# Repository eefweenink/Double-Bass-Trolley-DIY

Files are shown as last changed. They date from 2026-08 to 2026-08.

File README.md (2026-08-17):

# Double Bass Trolley DIY
**Manual + Downloads to Build Your Own Double Bass Trolley** *(Work in Progress)*

---

## Introduction

About ten years ago, I purchased one of the last available **Double Trolley** models by [Marc Grue](https://www.doubletrolley.com). It was a fantastic combination: a trolley with large, sturdy wheels that made it easy to walk—even up and down stairs—with an integrated stool. While the seat took some getting used to (it’s a bit small), it worked perfectly for me.

However, over time, my Double Trolley has started to wear out. Unfortunately, it’s no longer available for purchase, and secondhand models are nearly impossible to find. I understand why: if something works well, you don’t just let it go.

After years of searching for a suitable replacement without success, I decided to take matters into my own hands and build one myself. For now, this design does not include a stool, but the flexibility of 3D printing means I can easily adapt it later. I might even integrate it with an existing stool, allowing me to transport both my double bass and stool as a single unit.

This is my current design, which I’m actively testing. My goal is to share the design, bill of materials (BOM), and STL files so that other double bassists can build and enjoy their own version.

Regards,  
Eef

Double Bass Trolley Design

---

## Wheel Selection and Bearing Housing

### Wheel Choice
Without wheels, there’s no trolley. **12-inch wheels** are ideal: large enough to clear bumps but not so large that they compromise flexibility. This size also makes them perfect for navigating stairs.

For reference, [this Amazon listing](https://www.amazon.nl/Achterwiel-reservewiel-fietsbanden-veelzijdige-toepassing/dp/B0F9J1QZNZ) shows what these wheels look like. I found mine on **Marktplaats** (a Dutch second-hand marketplace), attached to a child’s bike.

### Wheel Construction
The wheel (plastic) contains two **6001ZZ bearings** pressed into either side, with the following dimensions:
- **Outer diameter**: 28 mm
- **Inner diameter**: 12 mm
- **Height**: 8 mm
- **Outer diameter of the inner ring**: 16.5 mm

### Securing the Wheel
To secure the wheel unilaterally in a tube, I use **M12 bolts** and 3D-printed bushings/plugs. The assembly (from left to right) consists of:
1. A **seal** that fits inside/on the tube.
2. A **flexible ring** that fits snugly into the bushing.
3. A **cone** that pushes the ring outward, clamping it in place.
4. A **self-locking nut** that holds the wheel in place while pressing all components together.

Assembly Diagram

To ensure this works with a single bolt, the design must include a column of components that can push against each other **without displacing or clamping the bearings**. This is achieved with the following structure:
- **Green**: The axle (an M12 bolt).
- **Red**: The bearings.
- **Blue**:
  - **Shim rings** (middle section): Must fit precisely on the inner ring of the bearing.
  - **Bearing housing**: Fits snugly on the inner ring and transfers pressure to the tube seal.

Bearing Housing Diagram

### Dimensions and Tolerances
- **General tolerance**: ±0.1 mm
- **Shim rings**:
  - **Inner diameter**: Slightly larger than 12 mm (target: **12.1 mm**).
  - **Outer diameter**: Maximum **17 mm**.
  - **Thickness**: **1.5–2 mm**.
- **Bearing housing**:
  - **Inner diameter**: Slightly larger than 12 mm (target: **12.1 mm**).
  - **Outer diameter**: Can be larger (up to **20 mm**; a wall thickness of **3–4 mm** is substantial).
    - *Note*: If the outer diameter exceeds 17 mm, **chamfer the ends** to avoid pressing on the wrong parts of the bearings.
  - **Thickness**: **34 mm** (so the total height of two bearings (2 × 8 mm) + housing equals **50 mm**).
    - **Important**: Measure first! Depending on the wheels, the thickness might need slight adjustment to avoid pressure on the bearings. Use your slicer to scale the model to the correct size if necessary.

Dimensions Diagram

> *The bearing housing and shim rings can be 3D printed or made of metal. My suggestion is to 3D print the bearing housing and use metal shims (see BOM list).*

---

## Materials Used

### Structural Components
- **Aluminum tube**:
  - **Outer diameter**: 33.3 mm
  - **Wall thickness**: 3 mm
  - **Purpose**: Used as the axle for mounting the wheels (see [Securing the Wheel](#securing-the-wheel)). Together with three other sections, it forms a sturdy rectangular frame that serves as the base of the trolley.
  - **Dimensions**:
    - **Axle length**: 38 cm (for my double bass in its bag).
    - **Vertical tubes**: 50 cm each (two pieces). May also be longer, about 65 cm so the top crossbar comes above the upper bout.
    - **Top crossbar**: ~31.3 cm (calculated as `38 cm - (2 × 33.3 mm)`).
- **Tyleen tubing**:
  - **Diameter**: 20.2 mm
  - **Purpose**: Used to build the side supports. This tubing has a **fixed curvature**, so it is important to rotate the pieces favorably during assembly.
 
- **Underfloor heating hose**:
  - **Diameter**: 16 mm
  - **Purpose**: The double bass rests on **half-moon-shaped parts** that are held together by this hose. See the image below for clarification.

  Half-moon shaped parts with hose

### 3D-Printed and Fastening Components
- **PETG filament**:
  - All couplings and connecting parts are 3D-printed using PETG.
  - **Printer volume**: 12 × 12 × 12 cm (all parts fit within this build volume, so no large printer is required).
- **Fastening cord**:
  - **Material**: 3.5 mm **paracord** (with a tensile strength of **150 kg**, more than sufficient for a double bass).
  - **Setup**:
    - **Lower loop**: Passes through the tubes and around the end pin.
    - **Upper loop**: Passes through the tubes and, using a **"spin elastic/span band"**, secures the neck.
    - Both loops pull in **opposite directions**, pressing the tube system firmly together toward the center.

### Additional Hardware
- **Metal hook**: Used to attach the cord to the end pin.
- **2 × M12 bolts**: For securing the wheel assembly.
- **4 × shim rings**: Prevent the force from the wheel mounting from pressing on the outer side of the bearings.

---

## End Hook and Accessories for Easy Spin Attachment
Printing Setup

The trolley is secured at the bottom with a hook around the **end pin**. Finding a well-fitting hook for this purpose isn’t straightforward, but this [hook from Amazon](https://www.amazon.nl/dp/B0C6HJWLKB) works reasonably well.

However, during use, the cord tends to slip between the iron wires of the hook, causing it to bend out of shape. To solve this, I designed a **protective "donut"** that shields the hook.
End pin hook with protective donut

### Printing the Donut
To print the donut:
1. **Positioning the hook**: The hook must be placed at the correct height inside the donut. This is easily achieved by using a **pause feature in the slicer**.
2. **Support structure**: Add **manual support** (only for the bottom surface, using the "tree" support type) to the donut in the slicer.
3. **Alignment tool**: Use a **1 mm thin rod** of the correct length to ensure the donut is printed at the right height.
4. **Printing process**:
   - Pause the print at the designated height.
   - Insert the hook neatly into the donut.
   - Resume the print.
Hook Example

Donut and Hook Assembly

> **Note**: The same design is used to create rings for the **top section**, making it easy to hook in the spin elastic.
Donut Design

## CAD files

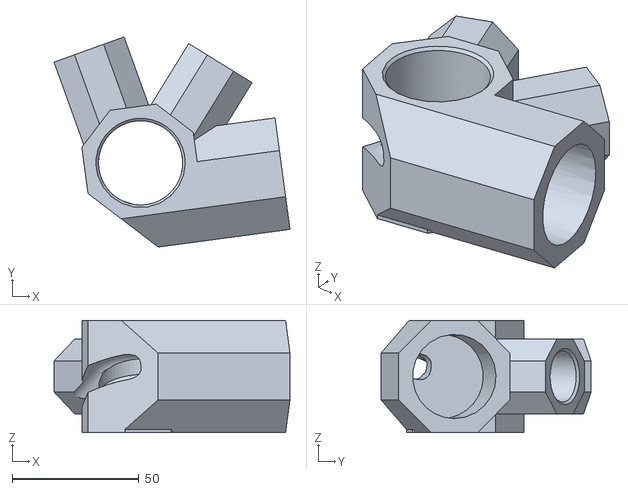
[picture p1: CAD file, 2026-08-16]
STL's/Alu construct/axle alu connector R (1x).stl
93.1 x 82.9 x 44.3

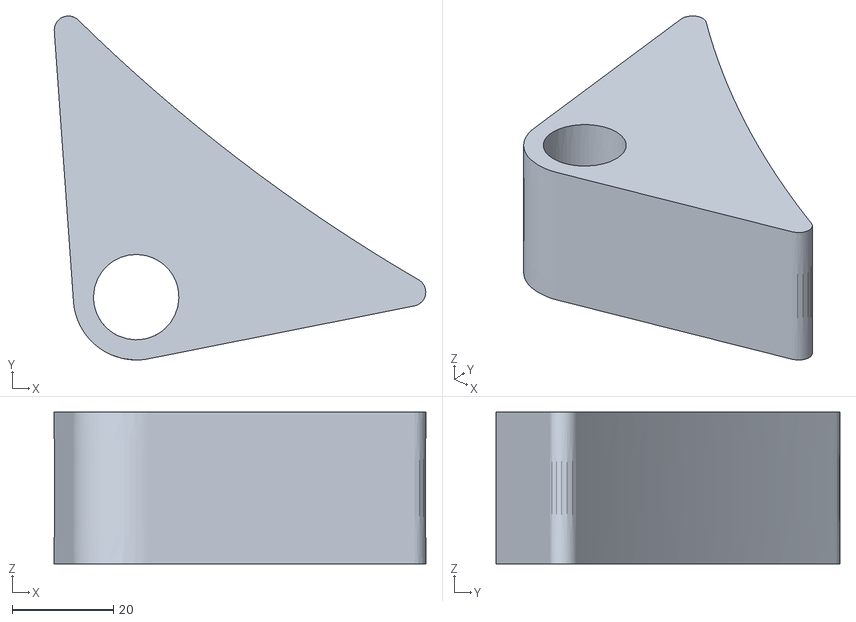
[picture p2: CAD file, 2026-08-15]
STL's/holder/bass holder (4x).stl
73.6 x 68.1 x 30.0

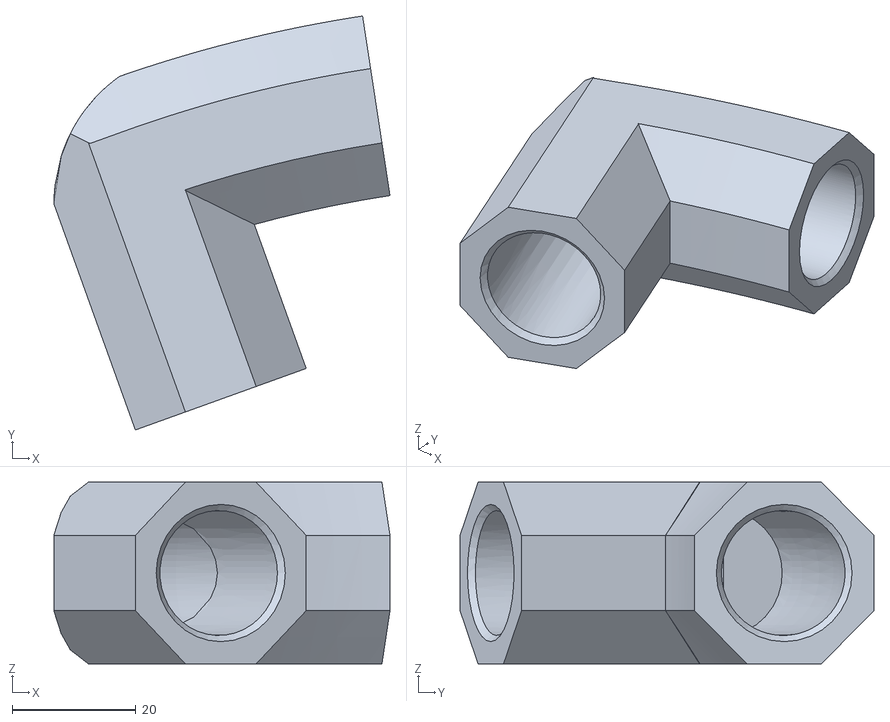
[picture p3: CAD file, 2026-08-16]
STL's/Sideskirt/skirt - knee (2x).stl
54.3 x 67.0 x 29.4

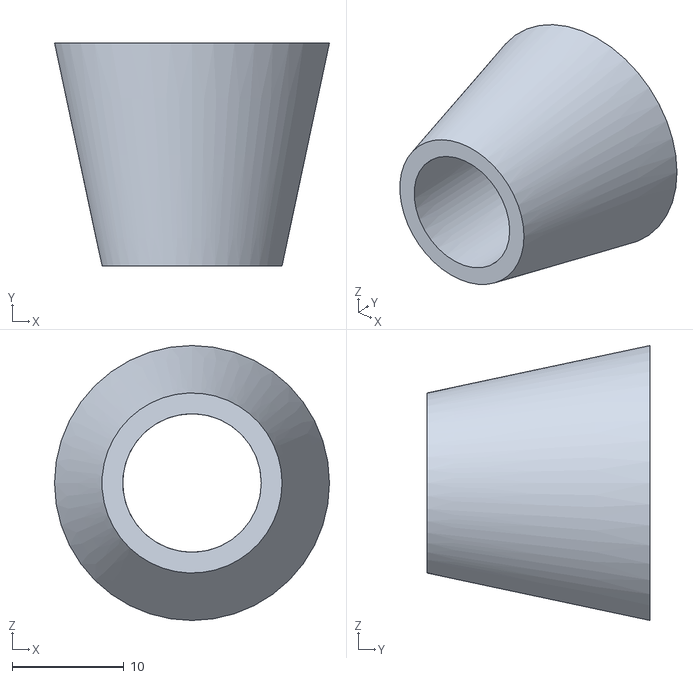
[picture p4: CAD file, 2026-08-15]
STL's/wheel-axle/wheel-axle plug tapered part (2x).stl
24.6 x 20.0 x 24.6

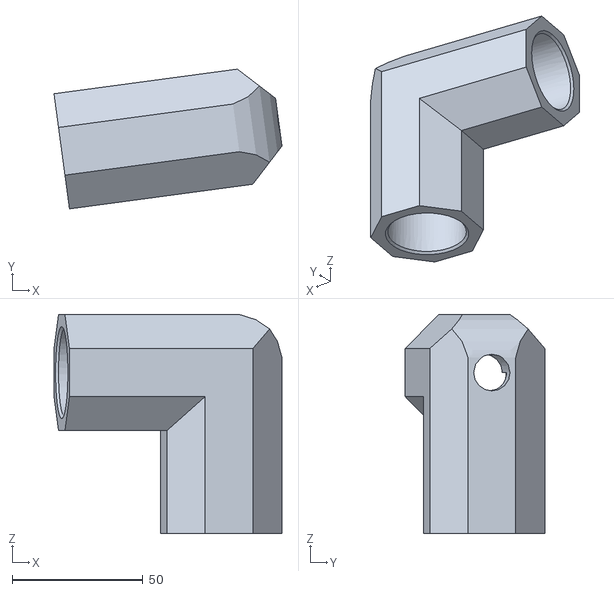
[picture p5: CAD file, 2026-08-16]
STL's/Alu construct/top bar alu connector (2x).stl
87.1 x 53.4 x 83.6

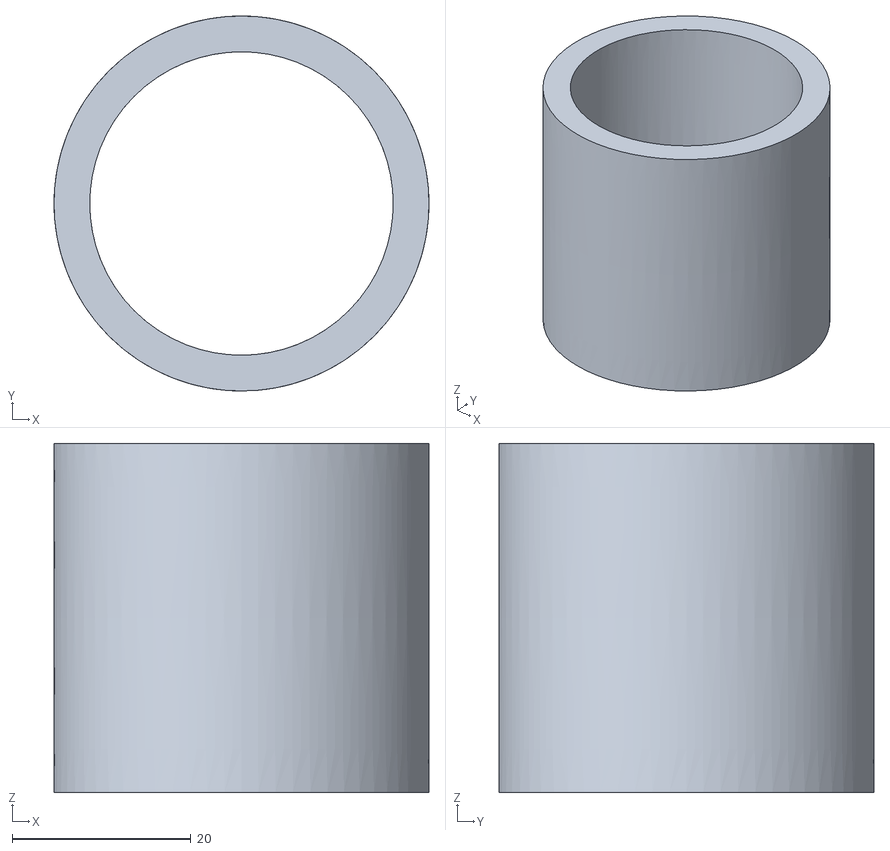
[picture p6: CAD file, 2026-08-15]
STL's/holder/spacer sleeve 39mm (2x).stl
41.9 x 41.9 x 39.0

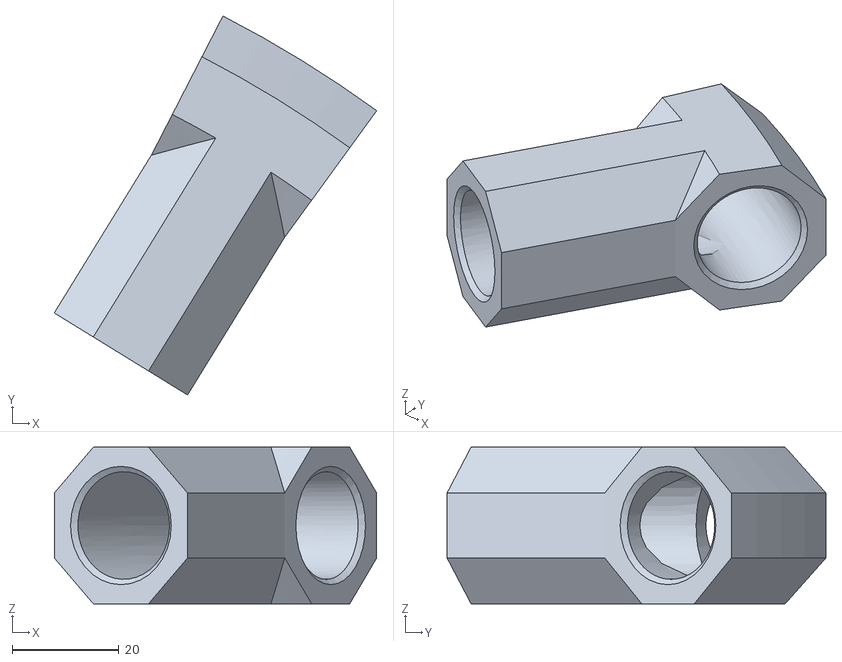
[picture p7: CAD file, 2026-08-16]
STL's/Sideskirt/skirt - T-part (2x).stl
60.5 x 71.1 x 29.4

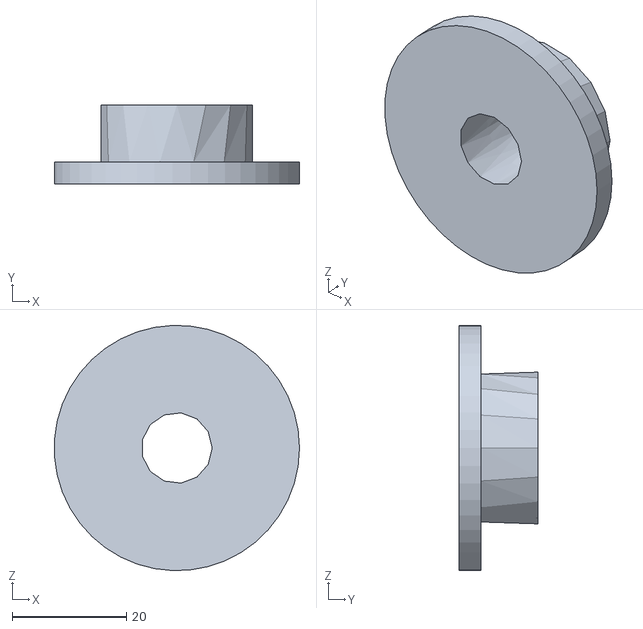
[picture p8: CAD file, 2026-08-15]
STL's/wheel-axle/wheel-axle plug outer part (2x).stl
42.9 x 13.9 x 43.0

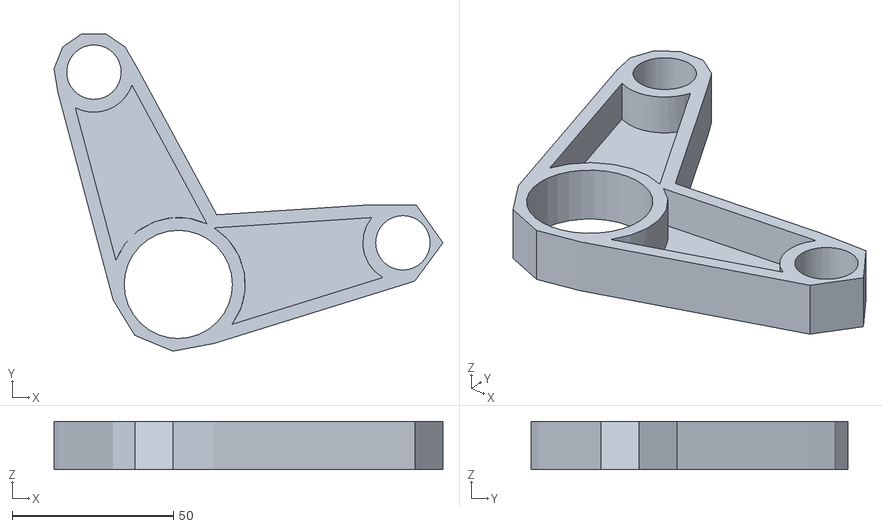
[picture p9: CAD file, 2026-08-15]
STL's/holder/axle part for bass holder (2x).stl
120.8 x 98.6 x 15.0

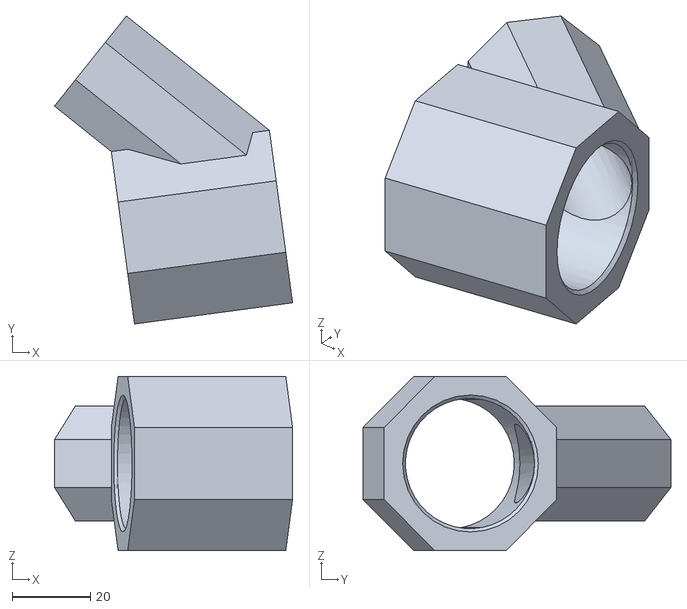
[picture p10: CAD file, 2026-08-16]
STL's/Sideskirt/Alu - skirt (2x).stl
60.7 x 78.5 x 44.3

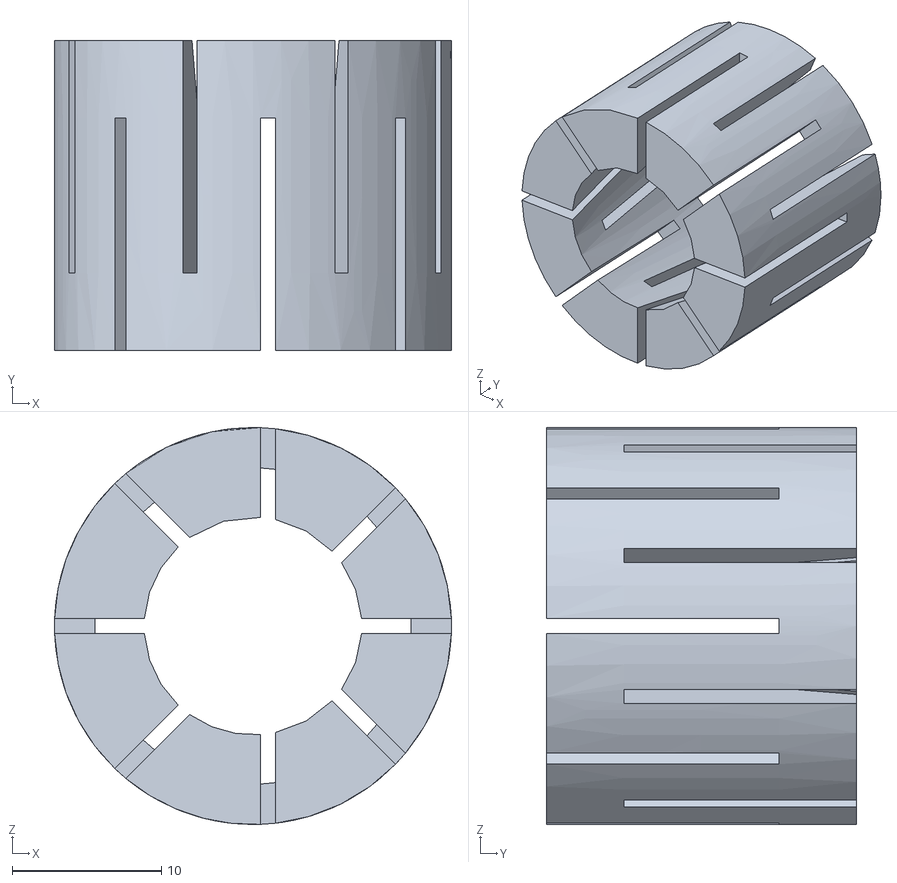
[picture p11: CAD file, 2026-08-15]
STL's/wheel-axle/wheel-axle plug expansion part (2x).stl
26.6 x 20.7 x 26.6

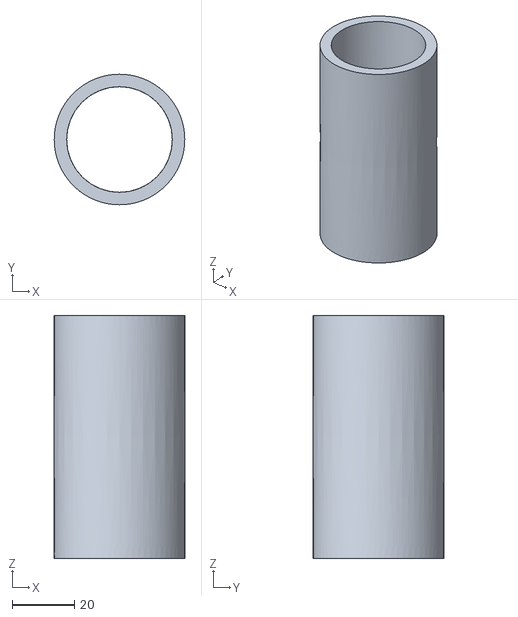
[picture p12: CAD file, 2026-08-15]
STL's/holder/spacer sleeve 78mm (4x).stl
41.9 x 41.9 x 78.0

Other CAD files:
STL's/Alu construct/axle alu connector L (1x).stl

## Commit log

2026-08-11 Clarify sourcing of 12-inch wheels in README
    Updated the wording for clarity regarding wheel sourcing.
2026-08-11 Revise README for wheel choice and image formatting
    Updated the wheel choice section for clarity and added a reference to the Dutch second-hand marketplace. Changed image syntax to markdown format.
2026-08-11 Update dimensions and tolerances in README
    Clarified dimensions and tolerances for shim rings and bearing housing in the README.
2026-08-11 Revise axle length and vertical tube dimensions
    Updated axle length description for double bass and added note about vertical tube length.
2026-08-13 Enhance README with donut printing instructions
    Added instructions for printing a protective donut for the hook and included images for clarity.
2026-08-13 Add image to printing process section
    Added an image to the printing process section in README.
2026-08-13 Revise materials list and enhance visuals
    Updated materials section for clarity and added images for donut and hook assembly.
2026-08-13 Enhance README with design details and image updates
    Updated README to include additional details about the design and construction of the Double Bass Trolley. Adjusted image formatting and added a note about wheel selection.
2026-08-13 Remove duplicate image from README section
    Removed duplicate image of the printing setup from the README.
2026-08-15 Create STL's
2026-08-15 Add 'test' to STL's file
